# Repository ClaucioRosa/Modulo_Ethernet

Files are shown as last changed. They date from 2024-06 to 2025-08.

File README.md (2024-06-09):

# Modulo_Ethernet
## Modulo Ethernet - Hardware 

<p align="center">
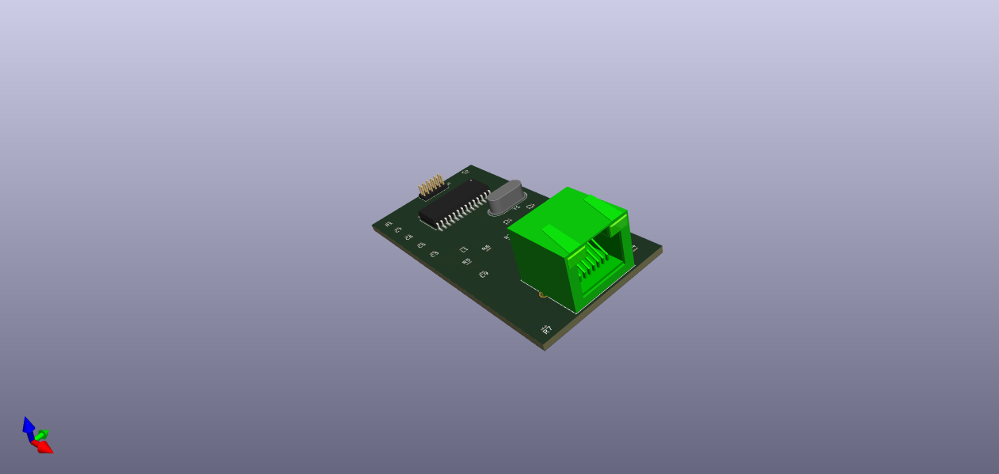
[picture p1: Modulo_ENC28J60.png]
  
</p>

## Descrição
O Módulo Ethernet é utilizado para atribuir aos microcontroladores a conexão ethernet / internet, tornando possível controlá-los a partir da rede interna (ethernet) ou através da rede externa (internet). 
Muitos projetos desenvolvidos com microcontroladores necessitam de acesso / controle de forma remota e ao utilizar o Módulo Ethernet essa necessidade é suprida de forma simples e prática, pois basta fazer as ligações entre o módulo e o microcontrolador, conectar o módulo ao roteador através de um cabo de rede com RJ45, inserir o código fonte correto no microcontrolador e usufruir dos benefícios.

Ao inserir o microcontrolador na internet, você pode acessá-lo de qualquer local do mundo, seja com um computador, smartphone ou tablet e obter informações ou solicitar que ações sejam executadas. Para projetos que envolvam integração entre o microcontrolador e aplicações Android ou iOS, o Módulo Ethernet se torna um membro importante do projeto.

## – Especificações e características:

#### – Controlador: ENC28J60
#### – Tensão de operação: 3,3VDC
#### – Velocidade de conexão: 10 / 100Mb
#### – Protocolos Suportados: TCP / IP
#### – Conexão com o Arduino através de SPI
#### – Possui cristal oscilador de 25MHz

https://ww1.microchip.com/downloads/en/DeviceDoc/39662c.pdf

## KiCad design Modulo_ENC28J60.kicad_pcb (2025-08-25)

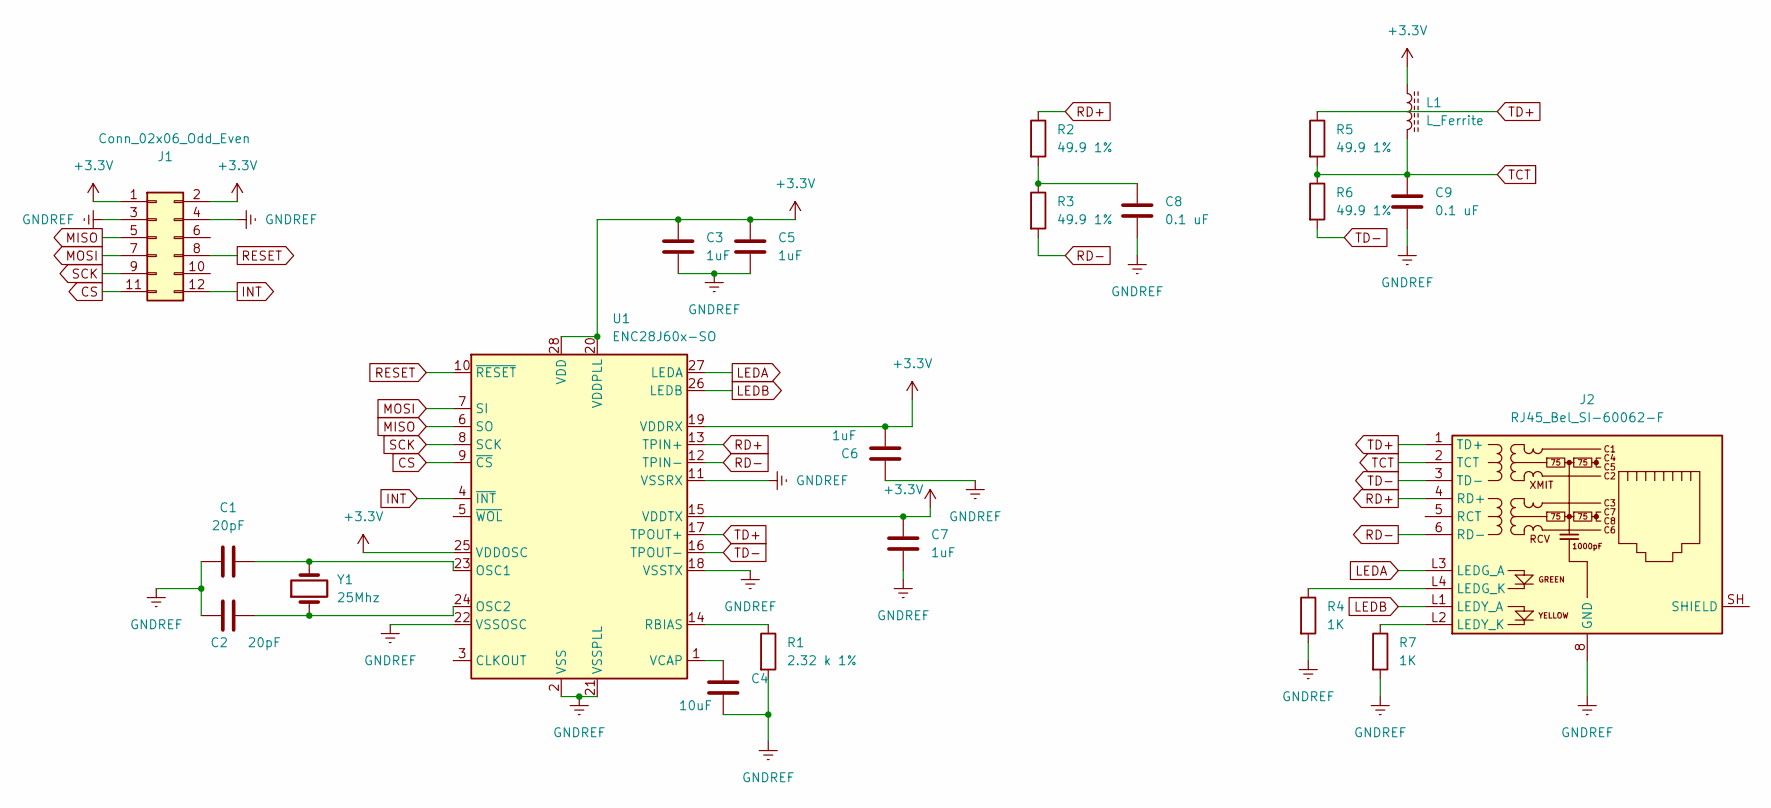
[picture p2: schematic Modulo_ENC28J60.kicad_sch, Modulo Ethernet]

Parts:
C1, C2: 20pF; R_1210_3225Metric_Pad1.30x2.65mm_HandSolder
C3, C5, C6, C7: 1uF; R_1210_3225Metric_Pad1.30x2.65mm_HandSolder
C4: 10uF; R_1210_3225Metric_Pad1.30x2.65mm_HandSolder
C8, C9: 0.1 uF; R_1210_3225Metric_Pad1.30x2.65mm_HandSolder
J1: Conn_02x06_Odd_Even; PinHeader_2x06_P1.27mm_Vertical
J2: RJ45_Bel_SI-60062-F
L1: L_Ferrite; R_1206_3216Metric_Pad1.30x1.75mm_HandSolder
R1: 2.32 k 1%; R_1210_3225Metric_Pad1.30x2.65mm_HandSolder
R2, R3, R5, R6: 49.9 1%; R_1210_3225Metric_Pad1.30x2.65mm_HandSolder
R4, R7: 1K; R_1210_3225Metric_Pad1.30x2.65mm_HandSolder
U1: ENC28J60x-SO; SOIC-28W_7.5x17.9mm_P1.27mm
Y1: 25Mhz; Crystal_HC49-4H_Vertical

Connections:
+3.3V: C3.1, C5.1, C6.1, C7.1, J1.1, J1.2, L1.1, U1.15 (VDDTX), U1.19 (VDDRX), U1.20 (VDDPLL), U1.25 (VDDOSC), U1.28 (VDD)
CS: J1.11, U1.9 (~CS)
GNDREF: C1.1, C2.1, C3.2, C4.2, C5.2, C6.2, C7.2, C8.2, C9.2, J1.3, J1.4, J2.8 (GND), R1.2, R4.2, R7.2, U1.2 (VSS), U1.11 (VSSRX), U1.18 (VSSTX), U1.21 (VSSPLL), U1.22 (VSSOSC)
INT: J1.12, U1.4 (~INT)
LEDA: J2.L3 (LEDG_A), U1.27 (LEDA)
LEDB: J2.L1 (LEDY_A), U1.26 (LEDB)
MISO: J1.5, U1.6 (SO)
MOSI: J1.7, U1.7 (SI)
unnamed: C1.2, U1.23 (OSC1), Y1.2
unnamed: C2.2, U1.24 (OSC2), Y1.1
unnamed: C4.1, U1.1 (VCAP)
unnamed: C8.1, R2.2, R3.1
unnamed: J2.L2 (LEDY_K), R7.1
unnamed: J2.L4 (LEDG_K), R4.1
unnamed: R1.1, U1.14 (RBIAS)
RD+: J2.4 (RD+), R2.1, U1.13 (TPIN+)
RD-: J2.6 (RD-), R3.2, U1.12 (TPIN-)
RESET: J1.8, U1.10 (~RESET)
SCK: J1.9, U1.8 (SCK)
TCT: C9.1, J2.2 (TCT), L1.2, R5.2, R6.1
TD+: J2.1 (TD+), R5.1, U1.17 (TPOUT+)
TD-: J2.3 (TD-), R6.2, U1.16 (TPOUT-)

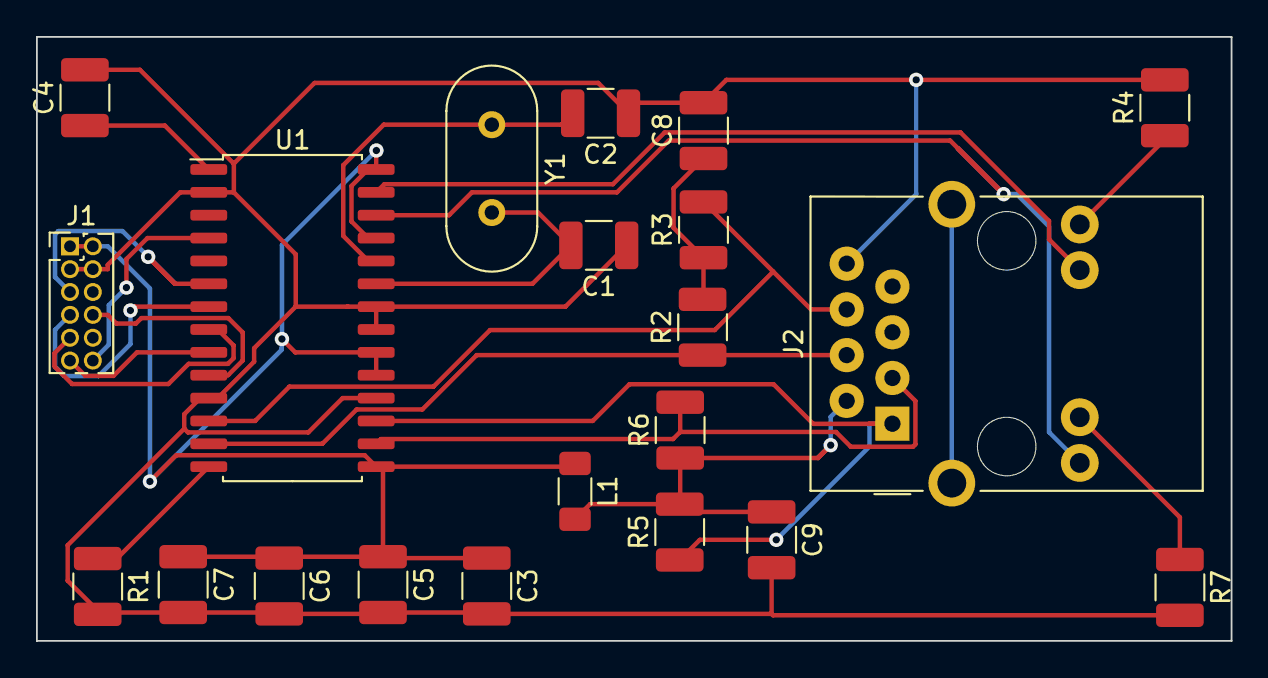
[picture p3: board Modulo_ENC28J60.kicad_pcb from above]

Board: 2 copper layers, 66.4 x 33.6 mm, 21 parts (0 on the bottom side), 22 nets.

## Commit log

2023-04-22 Arquivos Kicad 6
    [Modulo_ENC28J60.kicad_pcb, Modulo_ENC28J60.kicad_sch]
2025-08-25 Roteamento de trilhas
    [Modulo_ENC28J60.kicad_pcb, Modulo_ENC28J60.kicad_sch]
